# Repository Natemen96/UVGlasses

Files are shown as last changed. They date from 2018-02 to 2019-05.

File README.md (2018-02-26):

# UVGlasses
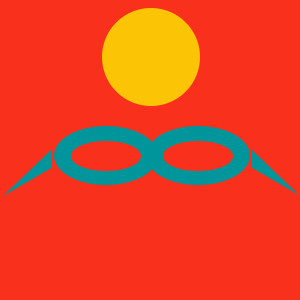
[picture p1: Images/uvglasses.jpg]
UVGlasses Logo


In 2014 **76,665** people in the United States were diagnosed with skin cancer

In 2014 **9,324** people in the United States died from skin cancer

The CDC recommends that the best method of prevention of melanoma is avoiding the sun, and as little as 15 minutes of exposure to the sun can be enough to damage the skin

The UV Glasses is our solution this issue, it's a wearable device that provide a convenient and innovative means of monitoring harmful UV ray exposure while presenting data real-time via mobile device.

UVGlasses Demo
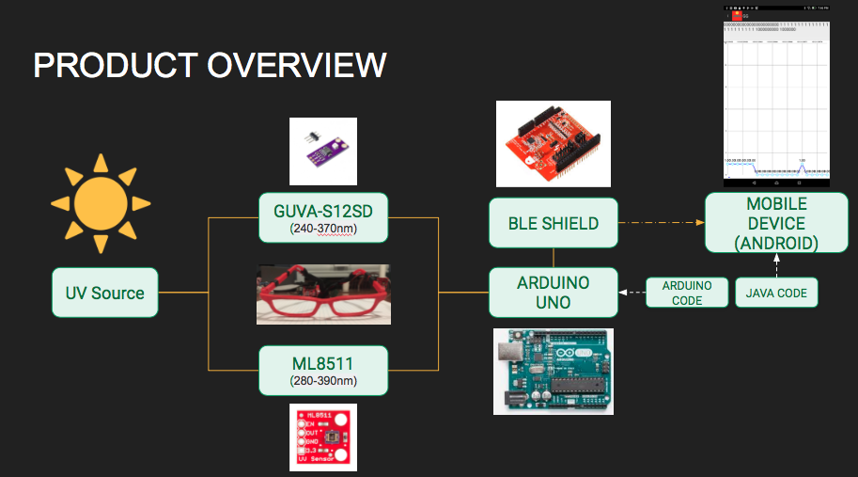
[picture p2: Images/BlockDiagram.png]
UVGlasses BlockDiagram

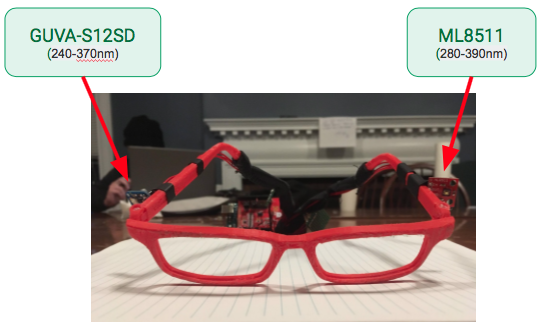
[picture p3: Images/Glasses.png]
UVGlasses Glasses

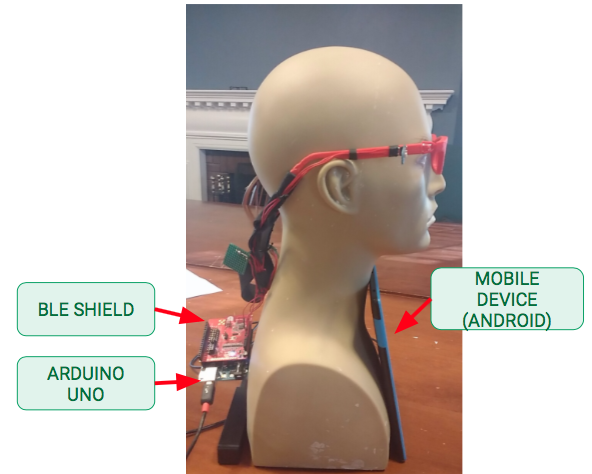
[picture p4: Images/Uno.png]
UVGlasses Uno


**FUTURE DEVELOPMENTS**

•Reduce product size

•Mobile device notification alerts

•Enable users to save data for further analysis

•Expand app functionality to iOS platforms

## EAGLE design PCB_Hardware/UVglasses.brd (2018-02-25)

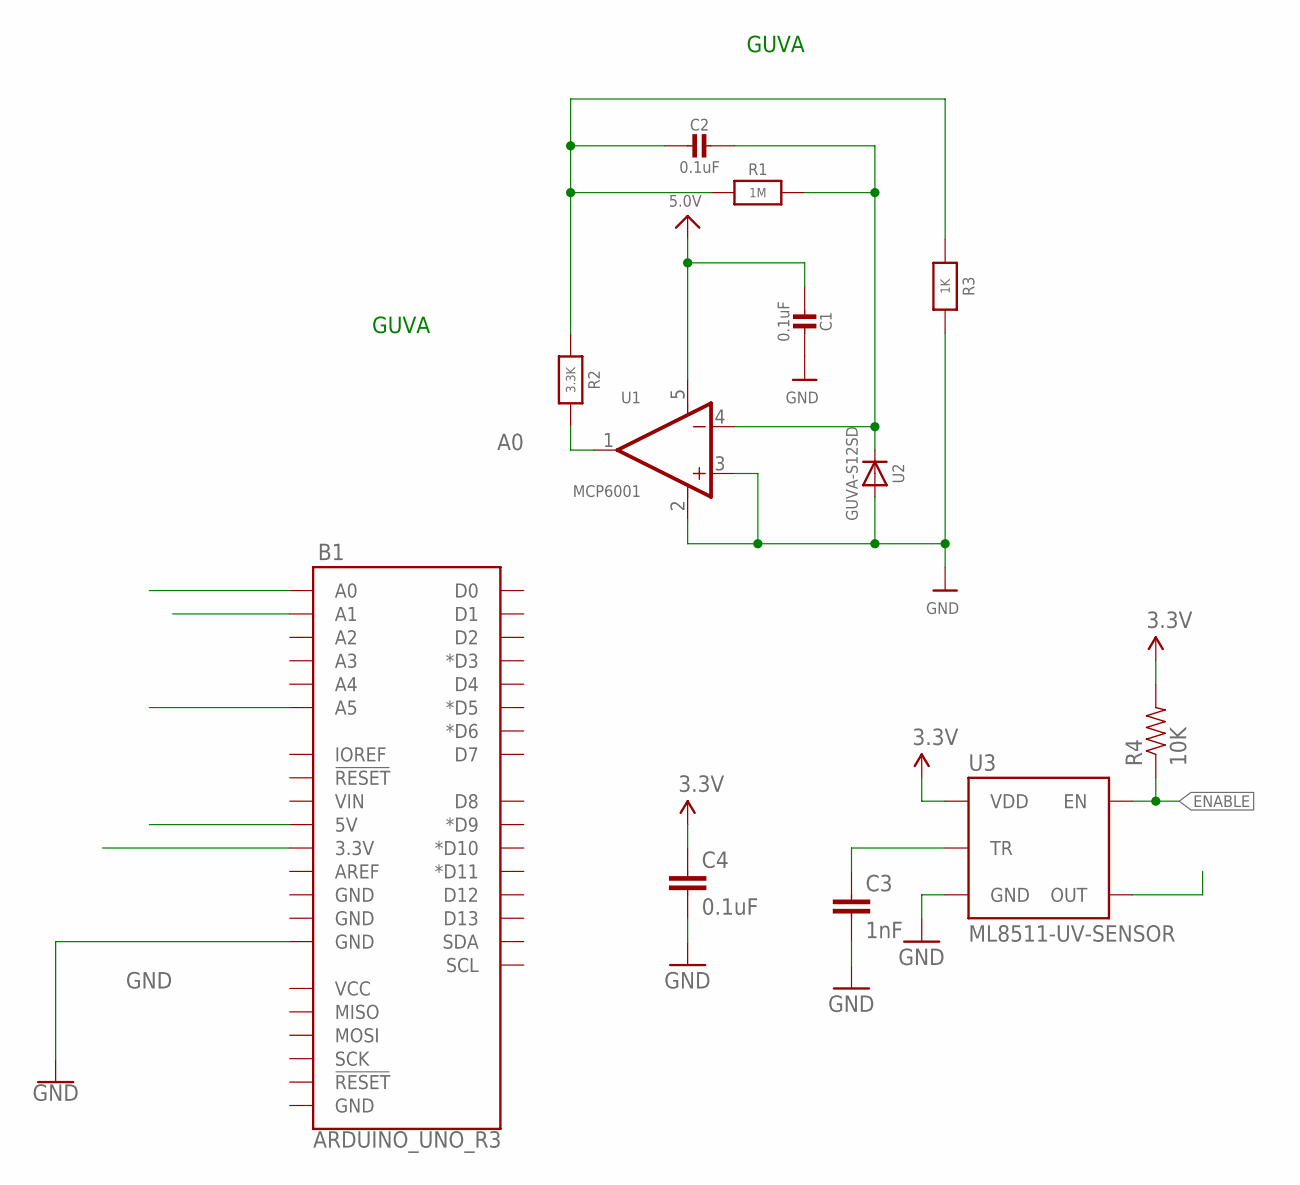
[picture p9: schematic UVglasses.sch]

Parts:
B1: ARDUINO_UNO_R3; ARDUINO_R3
C1, C2: 0.1uF; 0805-NO
C3: 1nF; 0603-CAP
C4: 0.1uF; 0603-CAP
R1: 1M; 0805-NO
R2: 3.3K; 0805-NO
R3: 1K; 0805-NO
R4: 10K; 0603-RES
U1: MCP6001; SOT23-5
U2: GUVA-S12SD
U3: ML8511-UV-SENSOR; ML8511

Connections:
3.3V: B1.3.3V, B1.A5, C4.1, R4.2, U3.7 (VDD)
5.0V: B1.5V, C1.1, U1.5 (V+)
A0: B1.A0, R2.1, U1.1 (OUT)
A1: B1.A1, U3.8 (OUT)
ENABLE: R4.1, U3.4 (EN)
GND: B1.GND@2 (GND), C1.2, C3.2, C4.2, R3.1, U1.2 (V-), U1.3 (+IN), U2.A, U3.5 (GND)
unnamed: C2.1, R1.2, R2.2, R3.2
unnamed: C2.2, R1.1, U1.4 (-IN), U2.K (C)
unnamed: C3.1, U3.10 (TR)

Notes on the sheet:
GUVA

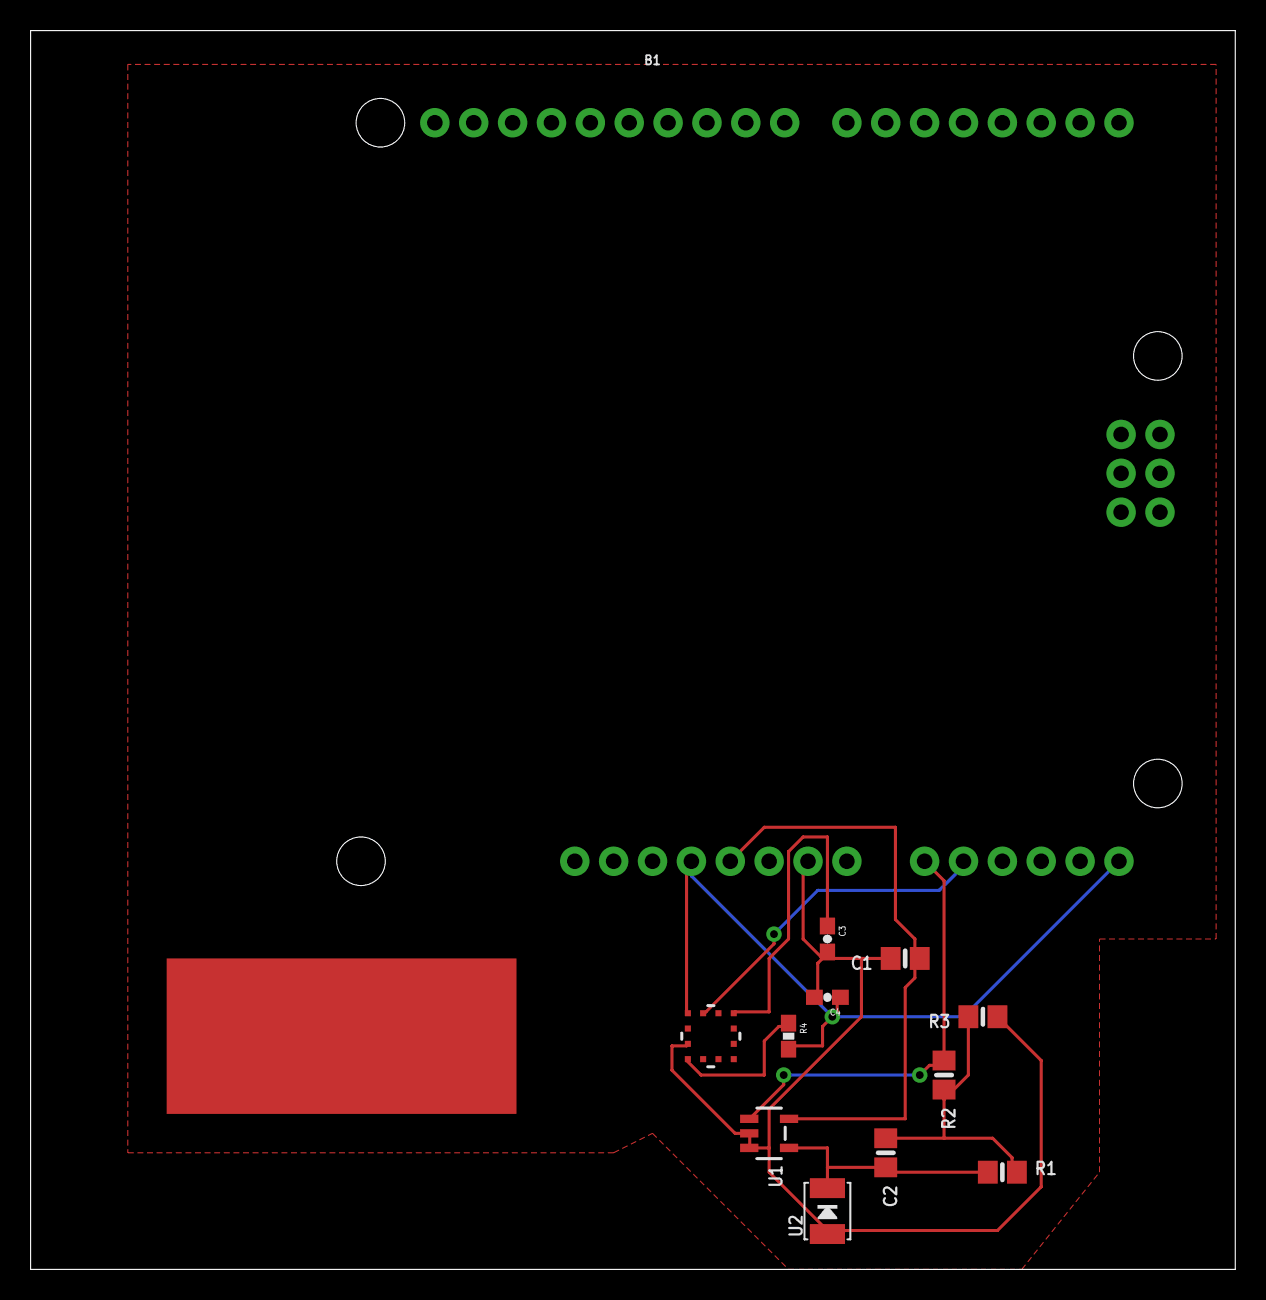
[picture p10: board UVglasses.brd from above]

Board: 2 copper layers, 78.7 x 81.0 mm, 12 parts (0 on the bottom side), 9 nets.

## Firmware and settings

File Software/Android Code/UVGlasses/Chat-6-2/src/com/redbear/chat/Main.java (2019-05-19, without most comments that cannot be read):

package com.redbear.chat;

import java.util.ArrayList;
import java.util.List;
import java.util.Timer;
import java.util.TimerTask;

import android.app.Activity;
import android.app.AlertDialog;
import android.app.Dialog;
import android.bluetooth.BluetoothAdapter;
import android.bluetooth.BluetoothDevice;
import android.bluetooth.BluetoothManager;
import android.content.Context;
import android.content.DialogInterface;
import android.content.DialogInterface.OnKeyListener;
import android.content.Intent;
import android.content.pm.PackageManager;
import android.os.Bundle;
import android.view.KeyEvent;
import android.view.View;
import android.view.View.OnClickListener;
import android.view.Window;
import android.widget.Button;
import android.widget.Toast;

public class Main extends Activity {
	private BluetoothAdapter mBluetoothAdapter;
	private static final int REQUEST_ENABLE_BT = 1;
	private static final long SCAN_PERIOD = 3000;
	private Dialog mDialog;
	public static List<BluetoothDevice> mDevices = new ArrayList<BluetoothDevice>();
	public static Main instance = null;
	public static final  int taco = 0;

	@Override
	protected void onCreate(Bundle savedInstanceState) {
		super.onCreate(savedInstanceState);
		requestWindowFeature(Window.FEATURE_INDETERMINATE_PROGRESS);
		setContentView(R.layout.main);

		if (!getPackageManager().hasSystemFeature(
				PackageManager.FEATURE_BLUETOOTH_LE)) {
			Toast.makeText(this, "Ble not supported", Toast.LENGTH_SHORT)
					.show();
			finish();
		}

		final BluetoothManager mBluetoothManager = (BluetoothManager) getSystemService(Context.BLUETOOTH_SERVICE);
		mBluetoothAdapter = mBluetoothManager.getAdapter();
		if (mBluetoothAdapter == null) {
			Toast.makeText(this, "Ble not supported", Toast.LENGTH_SHORT)
					.show();
			finish();
			return;
		}

		if (!mBluetoothAdapter.isEnabled()) {
			Intent enableBtIntent = new Intent(
					BluetoothAdapter.ACTION_REQUEST_ENABLE);
			startActivityForResult(enableBtIntent, REQUEST_ENABLE_BT);
		}

		Button btn = (Button)findViewById(R.id.btn);
		btn.setOnClickListener(new OnClickListener() {

			@Override
			public void onClick(View v) {
				scanLeDevice();

				showRoundProcessDialog(Main.this, R.layout.loading_process_dialog_anim);

				Timer mTimer = new Timer();
				mTimer.schedule(new TimerTask() {

					@Override
					public void run() {
						Intent deviceListIntent = new Intent(getApplicationContext(),
								Device.class);
						startActivity(deviceListIntent);
						mDialog.dismiss();
					}
				}, SCAN_PERIOD);
			}
		});

		scanLeDevice();

		showRoundProcessDialog(Main.this, R.layout.loading_process_dialog_anim);

		Timer mTimer = new Timer();
		mTimer.schedule(new TimerTask() {

			@Override
			public void run() {
				Intent deviceListIntent = new Intent(getApplicationContext(),
						Device.class);
				startActivity(deviceListIntent);
				mDialog.dismiss();
			}
		}, SCAN_PERIOD);

		instance = this;
	}

	public void showRoundProcessDialog(Context mContext, int layout) {
		OnKeyListener keyListener = new OnKeyListener() {
			@Override
			public boolean onKey(DialogInterface dialog, int keyCode,
								 KeyEvent event) {
				if (keyCode == KeyEvent.KEYCODE_HOME
						|| keyCode == KeyEvent.KEYCODE_SEARCH) {
					return true;
				}
				return false;
			}
		};

		mDialog = new AlertDialog.Builder(mContext).create();
		mDialog.setOnKeyListener(keyListener);
		mDialog.show();

		mDialog.setContentView(layout);
	}

	private void scanLeDevice() {
		new Thread() {

			@Override
			public void run() {
				mBluetoothAdapter.startLeScan(mLeScanCallback);

				try {
					Thread.sleep(SCAN_PERIOD);
				} catch (InterruptedException e) {
					e.printStackTrace();
				}

				mBluetoothAdapter.stopLeScan(mLeScanCallback);
			}
		}.start();
	}

	private BluetoothAdapter.LeScanCallback mLeScanCallback = new BluetoothAdapter.LeScanCallback() {

		@Override
		public void onLeScan(final BluetoothDevice device, final int rssi,
							 byte[] scanRecord) {
			runOnUiThread(new Runnable() {
				@Override
				public void run() {
					if (device != null) {
						if (mDevices.indexOf(device) == -1)
							mDevices.add(device);
					}
				}
			});
		}
	};

	@Override
	protected void onActivityResult(int requestCode, int resultCode, Intent data) {
		// User chose not to enable Bluetooth.
		if (requestCode == REQUEST_ENABLE_BT
				&& resultCode == Activity.RESULT_CANCELED) {
			finish();
			return;
		}
		super.onActivityResult(requestCode, resultCode, data);
	}

	@Override
	protected void onDestroy() {
		super.onDestroy();

		System.exit(0);
	}
}

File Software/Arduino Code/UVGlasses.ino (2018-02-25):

#include <SPI.h>
#include <boards.h>
#include <RBL_nRF8001.h>

unsigned char *bufferData[1]; //Buffer set up
//Hardware pin definitions
int uvoutML = A1; //Output from the ML sensor
int ref_3V3ML = A5; //3.3V power on the Arduino board for ML sensor

void setup() {
  Serial.begin(9600);
  ble_set_name("GG");
  // start BLE
  ble_begin();
  //Set up pinmodes
  pinMode(uvoutML, INPUT);
  pinMode(ref_3V3ML, INPUT);
}

void loop() {
  //GUVA calculations
  float sensorVoltage;
  float sensorValue;
  sensorValue = averageAnalogRead(A0);
  sensorVoltage = sensorValue / 1024 * 3.3;
  int uvIndex = UVindexGUVA(sensorVoltage * 10);
  //ML calculations
  int uvLevel = averageAnalogRead(uvoutML);
  int refLevel = averageAnalogRead(ref_3V3ML);
  float outputVoltage = 3.3 / refLevel * uvLevel;
  float uvIntensity = mapfloat(outputVoltage, 0.99, 2.8, 0.0, 15.0); //Convert the voltage to a UV intensity level
  //uvINtensity and UVindex is the same since our sampling rate is only 1 second
  float avgUV = ((uvIntensity + uvIndex) / 2);
  //Convert for ble write
  char *bufferUV = UVvalue(avgUV);
  char *buffer1 =  int2uCharArray(bufferUV);
  bufferData[0] = buffer1;
  //Write to ble only if ble is connected
  if ( ble_connected() )
  {
    // write test data to BLE write buffer
    ble_write_bytes(bufferData[0], sizeof(bufferData[0]) );
  }
  // use built-in function to transmit data
  ble_do_events();
  delay(1000);
}


unsigned char* int2uCharArray(int value)
{
  //conver int to char via array buffer
  char buffer[1] = {0};
  unsigned char ubuffer[1] = {0};
  itoa(value, buffer, 10);
  for (int i = 0; i < 1; i++)
    ubuffer[i] = buffer[i] - 48; //Fixed values

  for (int i = 0; i < 1; i++)
    Serial.println(ubuffer[i]);

  return ubuffer;
}

float UVindexGUVA(float sensorVoltage) {
  //Using UV index chart, return values of UV Index based on Voltage
  if (sensorVoltage >= 1.17 )
  {
    return 11.00;
  }
  else if (sensorVoltage >= 1.079 )
  {
    return 10.00;
  }
  else if (sensorVoltage >= .976 )
  {
    return 9.00;
  }
  else if (sensorVoltage >= .881 )
  {
    return 8.00;
  }
  else if (sensorVoltage >= .795 )
  {
    return 7.00;
  }
  else if (sensorVoltage >= .696 )
  {
    return 6.00;
  }
  else if (sensorVoltage >= .606 )
  {
    return 5.00;
  }
  else if (sensorVoltage >= .503 )
  {
    return 4.00;
  }
  else if (sensorVoltage >= .408 )
  {
    return 3.00;
  }
  else if (sensorVoltage >= .318 )
  {
    return 2.00;
  }
  else if (sensorVoltage >= .227 )
  {
    return 1.00;
  }
  else
  {
    return 0.00;
  }
}

int averageAnalogRead(int pinToRead)
{
  //Give avg of 8 reading for more accurate data
  byte numberOfReadings = 8;
  unsigned int runningValue = 0;

  for (int x = 0 ; x < numberOfReadings ; x++)
    runningValue += analogRead(pinToRead);
  runningValue /= numberOfReadings;

  return (runningValue);
}

//The Arduino Map function but for floats
//From: http://forum.arduino.cc/index.php?topic=3922.0
float mapfloat(float x, float in_min, float in_max, float out_min, float out_max)
{
  return (x - in_min) * (out_max - out_min) / (in_max - in_min) + out_min;
}

char *UVvalue(float avgUV)
{
  //returns as a char *
  if (avgUV >= 11.01)
  {
    return 11;
  }
  else if (avgUV >= 10.01)
  {
    return 10;
  }
  else if (avgUV >= 9.01)
  {
    return 9;
  }
  else if (avgUV >= 8.01)
  {
    return 8;
  }
  else if (avgUV >= 7.01)
  {
    return 7;
  }
  else if (avgUV >= 6.01)
  {
    return 6;
  }
  else if (avgUV >= 5.01)
  {
    return 5;
  }
  else if (avgUV >= 4.01)
  {
    return 4;
  }
  else if (avgUV >= 3.01)
  {
    return 3;
  }
  else if (avgUV >= 2.01)
  {
    return 2;
  }
  else if (avgUV >= 1.01)
  {
    return 1;
  }
  else
  {
    return 0;
  }
}

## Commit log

2018-02-25 Cleaned up Repository
    [UVglasses.brd, UVglasses.sch]
2019-05-19 Issue with Github cloning
    [UVglasses.brd, UVglasses.sch]

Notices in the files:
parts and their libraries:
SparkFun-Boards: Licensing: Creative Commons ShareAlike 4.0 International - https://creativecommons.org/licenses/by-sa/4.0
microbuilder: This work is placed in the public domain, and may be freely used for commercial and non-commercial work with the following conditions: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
